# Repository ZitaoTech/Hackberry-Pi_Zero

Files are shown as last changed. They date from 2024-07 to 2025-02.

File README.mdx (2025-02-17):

# Hackberry-Pi_Zero
A handheld Linux terminal using Raspberry pi Zero 2W as Core with 4" 720X720 TFT display and the original BlackBerry Keyboard

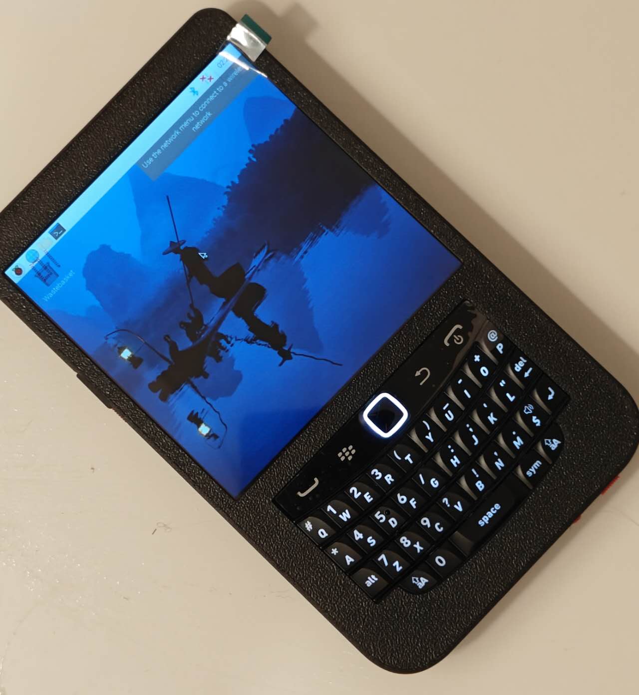
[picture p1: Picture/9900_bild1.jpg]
PTC3
  
  

### [Questions or need more info? Join my Discord Channel!](https://discord.gg/WzPthAmMbP)  
# <a name='About this handheld  '>About this handheld</a>
The main reason why I design and built this handheld cyberdeck is to treat this as a lernning tool and also a funny toy for the hackers. It is powered by a raspberry pi zero 2w and a 4" 720X720 TFT display. 

Here are some **Main Features:**  
**Main Processor**: Only compatible with Raspberry Pi Zero 2w.  
**Display**: 4" 720X720 high resolution TFT display.  
**Dual Swappable battery Design**: Replace your battery in 10 seconds without killing the power!  
**Battery Type**: Nokia BL-5C. You can buy it anywhere in the world.  
**Battery Life**: In my testing: 3.5 hours using the desktop, 5 hours on the commandline.  
**Keyboard Mouse Combo**: Yes, this cyberdeck has keyboard and mouse combo on board. You can choose blackberry Q10 or Q20 or 9900 keyboard.  
**Fully customizable keymap**: You can connect the keyboard with a computer and customizable the keymap through [VIAL](https://get.vial.today/) easily.  
**3 USB2.0 Ports**: This handheld has 3 USB2.0 Ports, you can use it with USB-Stick or 4G Module Dongle or any USB thing.  
**Charging Ampere**: Charge through the Type-C port. 1A charging rate; this handheld can be fully charged within 3 hours.  
**Stemma I2C Port**: This device has a Stemma I2C port on board, you can connect with any I2C sensors.  
**TF card Slot**: There is an external TF card Slot. You can replace your OS image very easily.  

## Block Diagram
Blockdiagramm_HackberryPi_Zero

# <a name='Get started  '>Get started   </a>  
### [Introductionvideo](https://www.youtube.com/watch?v=HDEBzaB1IcY&ab_channel=ZitaoTech)
### How to turn on the HackberryPi?  
Turn the red switch to the **right position** and then press the **red button** to the left side of the red switch to power the USB Hub Controller Chip otherwise the keyboard **can't be used!** At the same time the indicator for the battery voltage will be turned on.    
Turnon  
turnon
# <a name='Keyboard  '>Keyboard</a>
### [Video: Features about the keyboard](https://www.youtube.com/watch?v=mscH1y3DAzE&t=2s&ab_channel=ZitaoTech)
The keyboard type is blackberry Q10 or Q20 keyboard. Both have the same keyboard layout.  
There is a red switch on the left side to decide if the keyboard controller communicates with the HackberryPi or with other device through the USBC-Port underneath.  
The idea about this is you can connect the keyboard with your computer and customize the keymap using [VIAL](https://get.vial.today/) or the handheld can be used as an emergency keyboard mouse combo.  
keyboard
### How to change the keymap?  
Put the red switch to the lower position, connect the keyboard with your computer, open [VIAL page](https://vial.rocks/), then you can customize the keymap yourself.  


# <a name='Different Operating System  '>Different Operating System</a>
You can install Kali, Raspberrypi OS, or Retropi and many other OS into HackberryPi.  
[This page](https://github.com/ZitaoTech/Hackberry-Pi_Zero/tree/main/Screen) will tell you how to install the display driver in a different operating system.  
And [this page](https://github.com/ZitaoTech/Hackberry-Pi_Zero/tree/main/Basic-Setup) will tell you some basic settings on different OS to make HackberryPi have better performance. 
# <a name='Basic Tutorial  '>Basic Tutorial</a>
How to change font size in [terminal](https://askubuntu.com/questions/173220/how-do-i-change-the-font-or-the-font-size-in-the-tty-console)
# <a name='Dimension and Weight  '>Dimension and Weight</a>
Dimension of HackberryPi: 139.4x82x15.7mm  
Weight without battery: 151.7 Gram  
Weight with battery: 189.7 Gram  
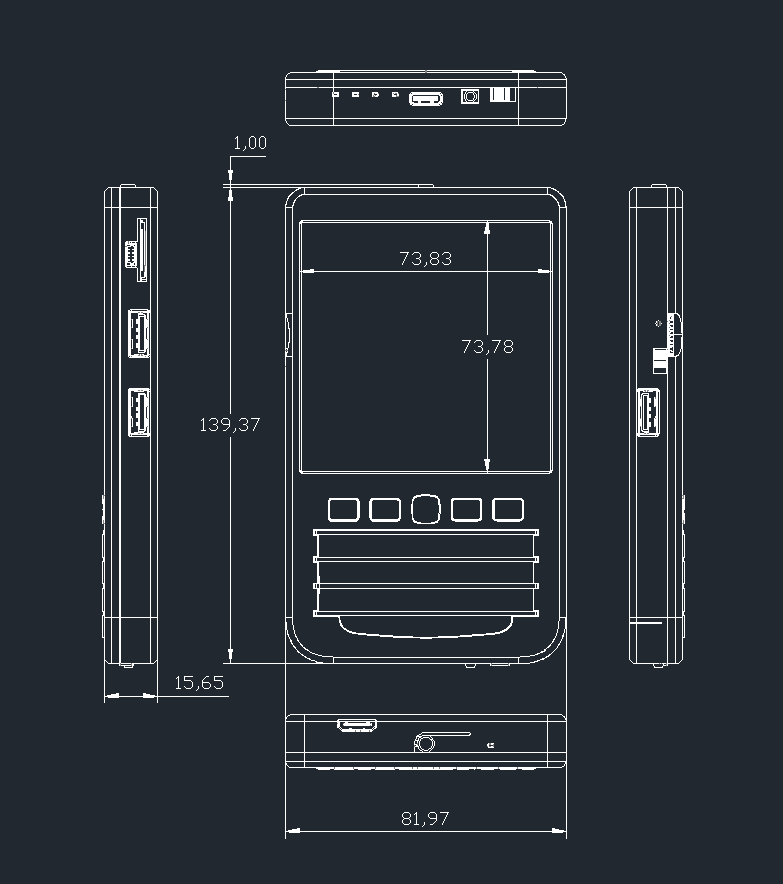
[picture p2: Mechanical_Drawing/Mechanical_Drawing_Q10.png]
  
# <a name='Where to buy  '>Where to buy</a>
### On Elecrow(ship with battery)
[BBQ10 keyboard version](https://www.elecrow.com/hackberrypi-zero-with-q10-keyboard.html)  
[BBQ20 keyboard version](https://www.elecrow.com/hackberrypi-zero-with-bbq20-keyboard.html)  
[BB9900 keyboard version](https://www.elecrow.com/hackberrypi-zero-with-bb9900-keyboard.html)
### On Tindie
[BBQ10 keyboard version](https://www.tindie.com/products/zitaotech/hackberrypi-cyberdeck-handheld-with-bbq10-keyboard/)  
[BBQ20 keyboard version](https://www.tindie.com/products/zitaotech/hackberrypi-cyberdeck-handheld-with-bbq20-keyboard/)  
[BB9900 keyboard version](https://www.tindie.com/products/zitaotech/hackberrypi-cyberdeck-handheld-with-bb9900-kbd/)

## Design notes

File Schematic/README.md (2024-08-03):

### Why no Gerber file?

Some parts like the display and the backlight brightness control chip are custom ordered parts. It's basically impossible to rebuild one even The PCB is ordered from PCBWay or JLCPCB.

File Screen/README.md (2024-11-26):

# This page will tell you the ways to install the display driver in different operating system and some using tips of the display  
### First you need to install the operating system you need into RaspberryPi, this is the [tutorial](https://www.raspberrypi.com/documentation/computers/getting-started.html#installing-the-operating-system), when you choose device, select Raspberry Pi Zero 2W.  
### There is a mini-HDMI port on the top side of HackberryPi. You can connect it with another screen. You can use the following commands to disable/enable the displaying.

```sh
vcgencmd display_power 0
vcgencmd display_power 1
```
### The default backlight brightness of the display after you turn HackberryPi on would be 50%. There is a physical button of the top side of HackberryPi. You can single press it to toggle the backlight of the display. You can also adjust the backlight brightness by long pressing the button: If you first long press the button the backlight brightness will slowly increase to 100%, if you now release the button and long press the button again, the backlight brightness of the display will slowly drop to 10%.  
# Raspberry Pi OS after 04/04/2022 or later  

Add the following line in `/boot/config.txt` in your TF card  

```sh
dtoverlay=vc4-kms-dpi-hyperpixel4sq
``` 
And the `config.txt` file will look like this:  
  
Follow the steps:  
Insert the TF card in to the slot  
Turn on the HackberryPi, the screen will be black, wait until the white led on top stop blinking.  
Turn off the HackberryPi and reboot.  
And then your HackberryPi will run Raspberry Pi OS on the screen.  
RaspberryPiOSfoto

# Kali Linux or Raspberry Pi OS before 04/04/2022   

### Step 1  
Add the following lines in `/boot/config.txt` in your TF card  

```sh
dtoverlay=hyperpixel4
overscan_left=0
overscan_right=0 
overscan_top=0
overscan_bottom=0
framebuffer_width=720
enable_dpi_lcd=1
display_default_lcd=1
dpi_group=2
dpi_mode=87
dpi_output_format=0x5f026
dpi_timings=720 0 20 20 40 720 0 15 15 15 0 0 0 60 0 36720000 4
```
And the `config.txt` file will look like this:  


### Step 2  
Download the `hyperpixel4.dtbo`file in this github page   
Put the `hyperpixel4.dtbo`file into `/boot/overlays`folder  
Now you can insert the TF card in to the slot and your HackberryPi will run Kali Linux on the screen.  
Kalilinux Foto
# RetroPi OS  
### Step 1  
Add the following lines in `/boot/config.txt` in your TF card  

```sh
dtoverlay=hyperpixel4
enable_dpi_lcd=1
dpi_group=2
dpi_mode=87
dpi_output_format=0x5f026
dpi_timings=720 0 20 20 40 720 0 15 15 15 0 0 0 60 0 36720000 4
```
And the `config.txt` file will look like this:  


### Step 2  
Download the `hyperpixel4.dtbo`file in this github page   
Put the `hyperpixel4.dtbo`file into `/boot/overlays`folder  
Now you can insert the TF card in to the slot and your HackberryPi will run RetroPi OS on the screen.  
RetroPiFoto

# DietPi  
DietPi is an extremely lightweight Debian OS, highly optimised for minimal CPU and RAM resource usage. The instruction is made by [Bjoern Franck](https://github.com/bjoernfranck)  
You can view the tutorial at this [page](https://github.com/bjoernfranck/HackberryPi/tree/main/DietPi)  


# Troubleshoot  
  
You might found your display flickering or flashing like this on the picture. This happens when the display driver is powered but no image signal coming through.  
It can usually happen when you flash a new SD card or wake up from screen blanking.  
The display can recover itsself when you put the device running like 1 hour, but you need to disable screen blanking first.  
Here are steps you need to do to disable screen blanking:  
[On RaspberryPi OS](https://github.com/raspberrypi/documentation/blob/develop/documentation/asciidoc/computers/configuration/screensaver.adoc)  
[On Kali](https://superuser.com/questions/1185747/how-do-i-disable-the-screensaver-lock-in-kali-linux)

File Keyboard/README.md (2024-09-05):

hackberrypiq10_vial.uf2: default firmware file for the keyboard controller chip(RP2040) on HackberryPi with BBQ10 keyboard  
hackberrypiq20_vial.uf2: default firmware file for the keyboard controller chip(RP2040) on HackberryPi with BBQ20 keyboard  
layout_hackberrypi_q10.vil: default keyboard layout setting file on VIAL for HackberryPi with BBQ10 keyboard  
layout_hackberrypi_q20.vil: default keyboard layout setting file on VIAL for HackberryPi with BBQ20 keyboard  

### How to use the .vil file?  
Let's say that you changed many keycodes and want to reset the keyboard layout  
First download vial app from [vial](https://get.vial.today/) homepage  
Install the vial app and open the app  
Then connect yor computer with Hackberry and in menu **file**->**Load saved layout** and select the .vil file, the keyboard layout will be reset.  

## Default Layout and Layers
### Layer0:
Keymap_Layer0

### Layer 1:
Keymap_Layer1

### Layer 2:
Keymap_Layer2

## Other Features
When holding Ctrl, mouse dpix2  
When holding Alt, mouse dpi/2  
When capslock, The trackpadbacklight will be turned on for Q10 version, and the backlight of the top row keys will be turned on for Q20 version. meanwhile the mouse will work as scroll wheel, you can browse a file quickly.  

The backlight of the keyboard will be turned off if you don't type anything for 30 seconds.

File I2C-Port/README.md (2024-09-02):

## How to use the I2C port on HackberryPi
First, don't enable I2C interface in raspi-config. Because the default I2C pins are used by the display. If you enable the I2C interface, the screen will be black. You need to connect HackberryPi to another display with an HDMI cable to disable the I2C interface to make it back.

The I2C pins on HackberryPi are: GPIO10 for I2C_SDA and GPIO11 for I2C_SCL  

There is a [STEMMA QT](https://learn.adafruit.com/introducing-adafruit-stemma-qt/what-is-stemma-qt) port on board, which means you can connect a sensor board with STEMMA QT port with HackberryPi through the I2C interface.  
On HackberryPi you need to open a terminal, and type:
``` sh
sudo ln -s /dev/i2c-11 /dev/i2c-1
```
to symlink i2c-11 to i2c-1 to fool any I2C devices into talking to the alternate one rather than the standard one.

Then you can just type this in a terminal:
``` sh
sudo i2cdetect -y 1
```
to check if the sensor is available.



If you want to undo this, you can simply delete the i2c-1 symlink file by typing in the terminal:
``` sh
sudo rm /dev/i2c-1
```

## One example about using this I2C port:  
[hack-environment-monitor](https://github.com/chriswilson2020/hack-environment-monitor/tree/main)

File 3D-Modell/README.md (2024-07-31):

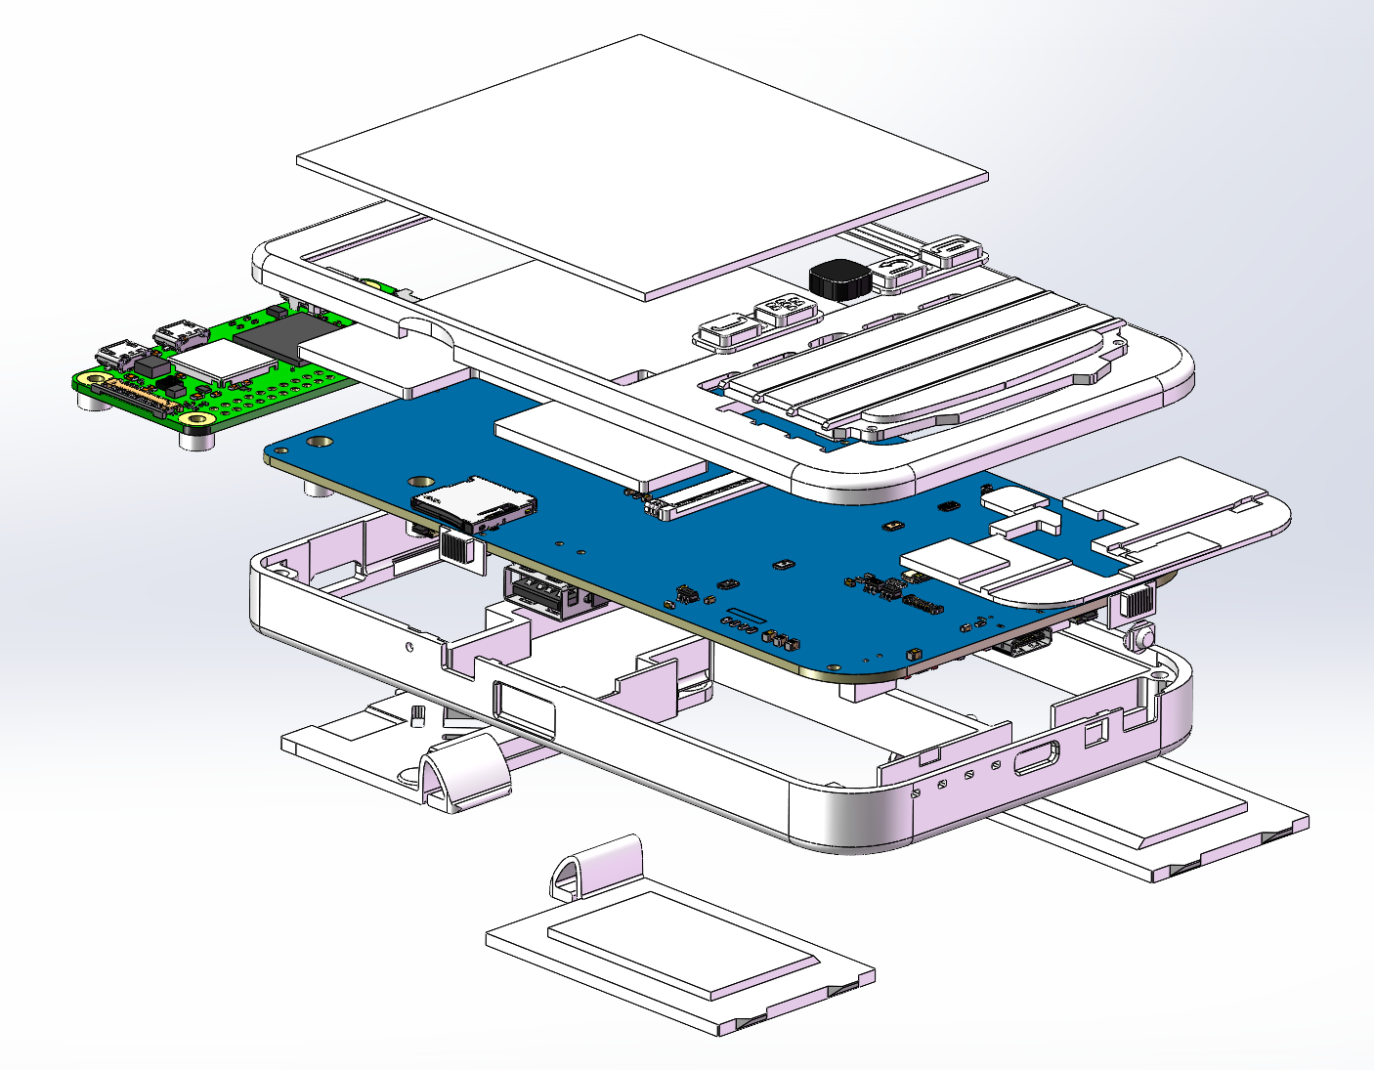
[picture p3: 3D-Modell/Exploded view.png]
exploded view


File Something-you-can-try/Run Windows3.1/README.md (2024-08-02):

### First, download dosbox app by

```sh
sudo apt-get install dosbox
```

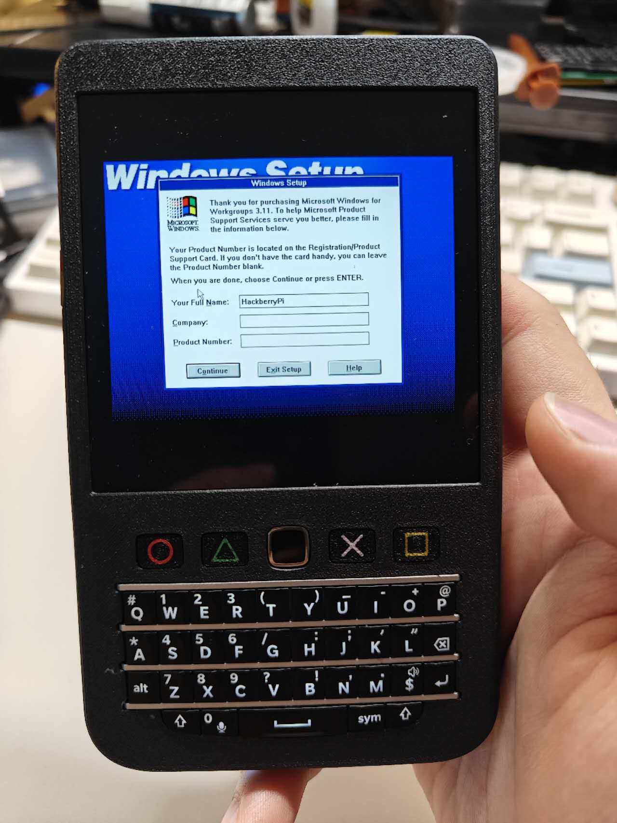
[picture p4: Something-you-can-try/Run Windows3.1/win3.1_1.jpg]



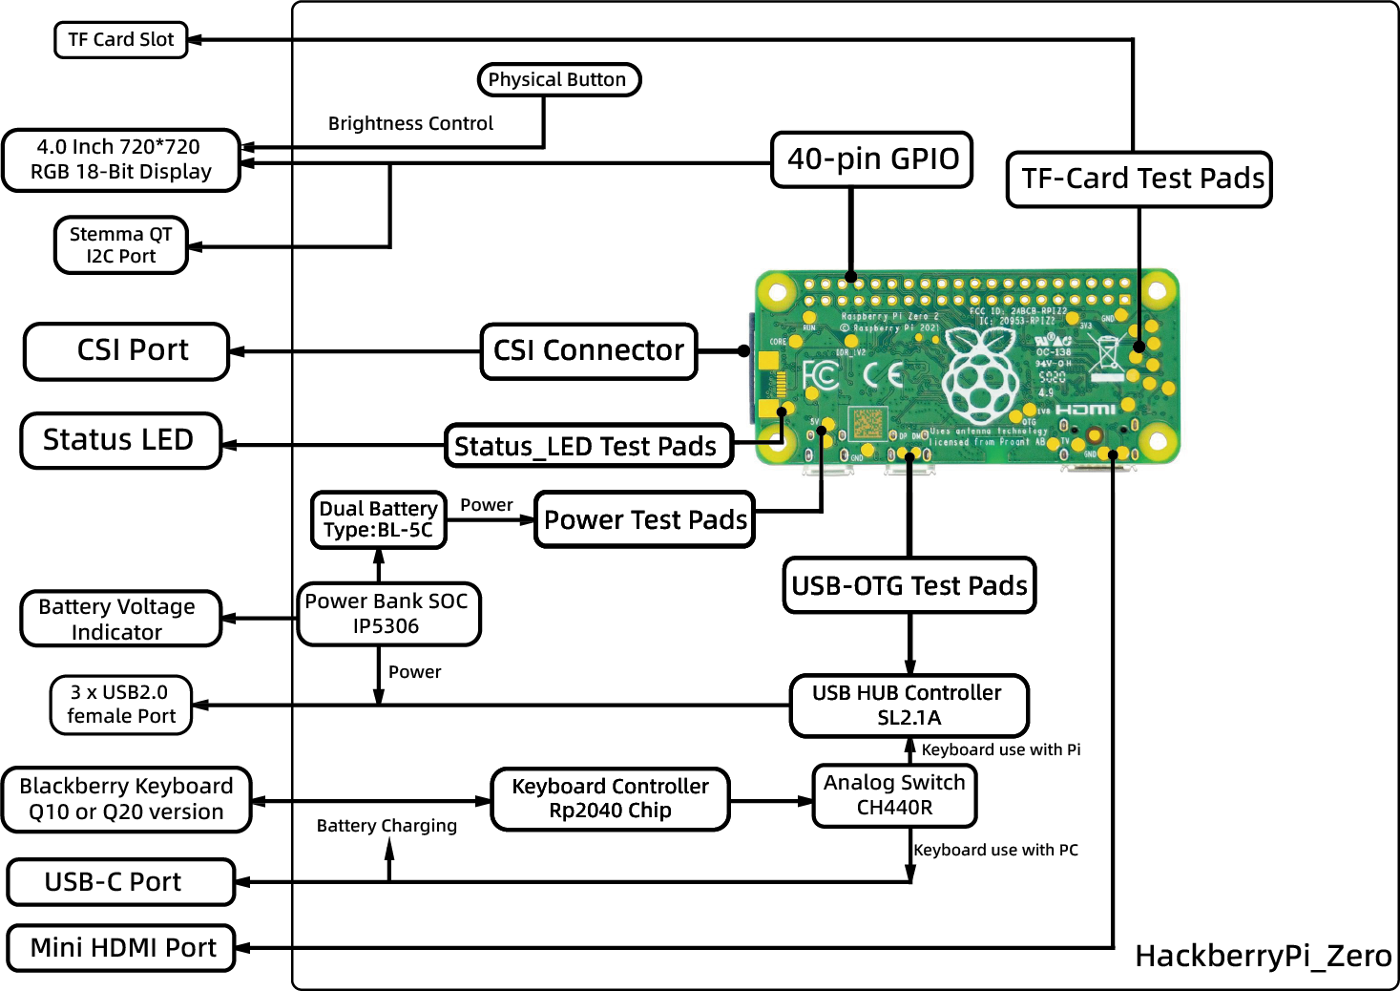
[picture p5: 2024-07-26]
Picture/Blockdiagramm_HackberryPi_Zero.png

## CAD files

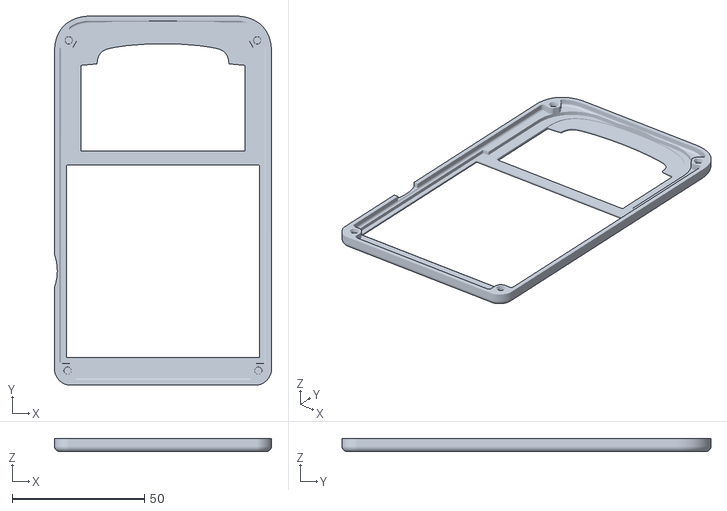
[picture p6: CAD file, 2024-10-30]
3D-Modell/Uppercase_9900_keyboard_version.stl
82.0 x 139.4 x 4.95

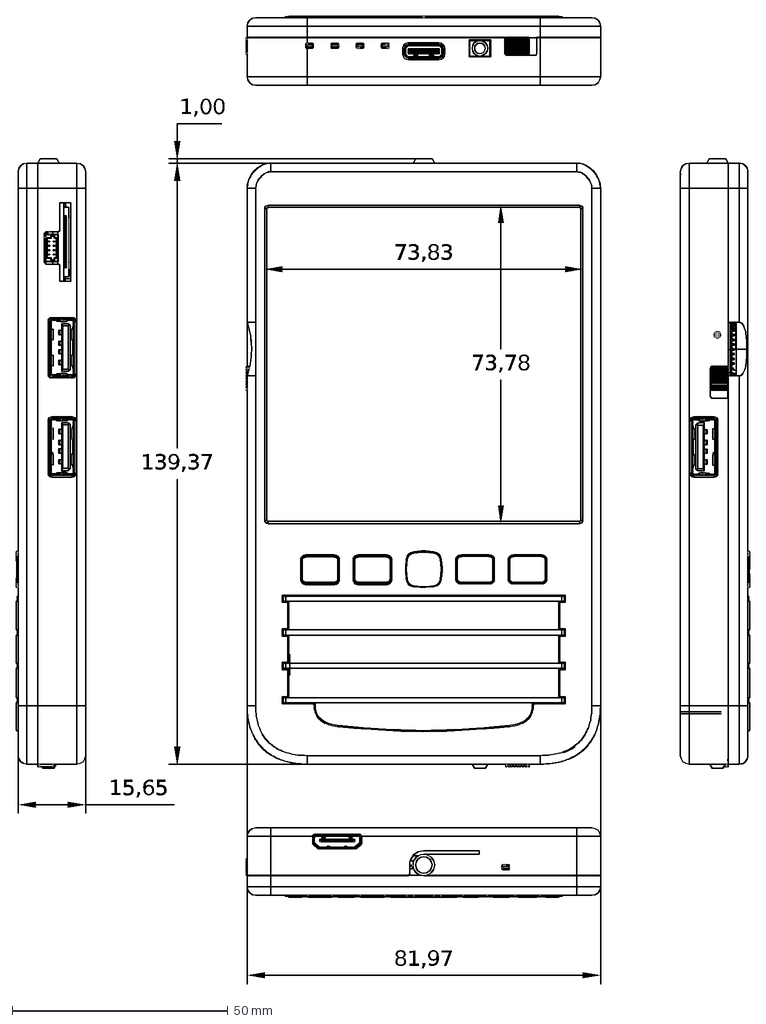
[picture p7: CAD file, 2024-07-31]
Mechanical_Drawing/HackberryPi_Q10.dxf
15,65
139,37
1,00
73,83
73,78
81,97

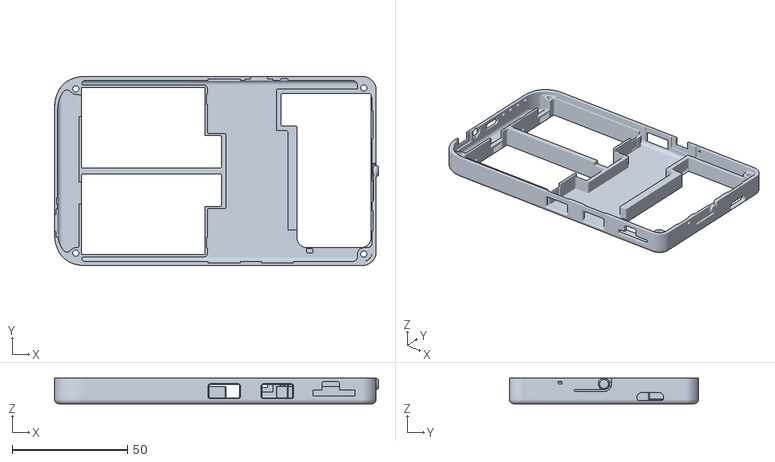
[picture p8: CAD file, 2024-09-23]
3D-Modell/Hackberry_LowerCase_fits_for_3_version.stl
140.4 x 82.0 x 11.1

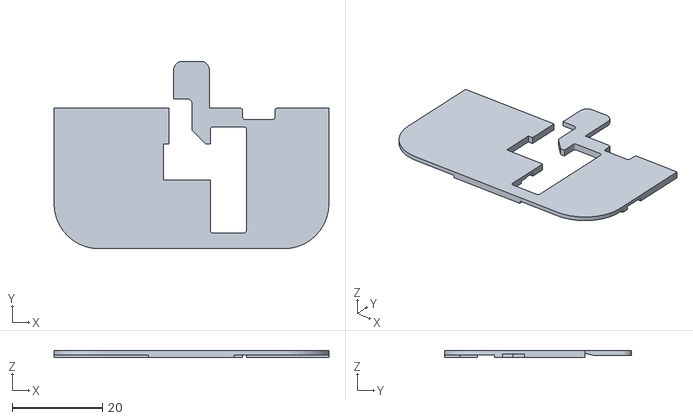
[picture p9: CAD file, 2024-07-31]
3D-Modell/Under_keyboard_support_Q10.STL
61.0 x 41.6 x 1.55

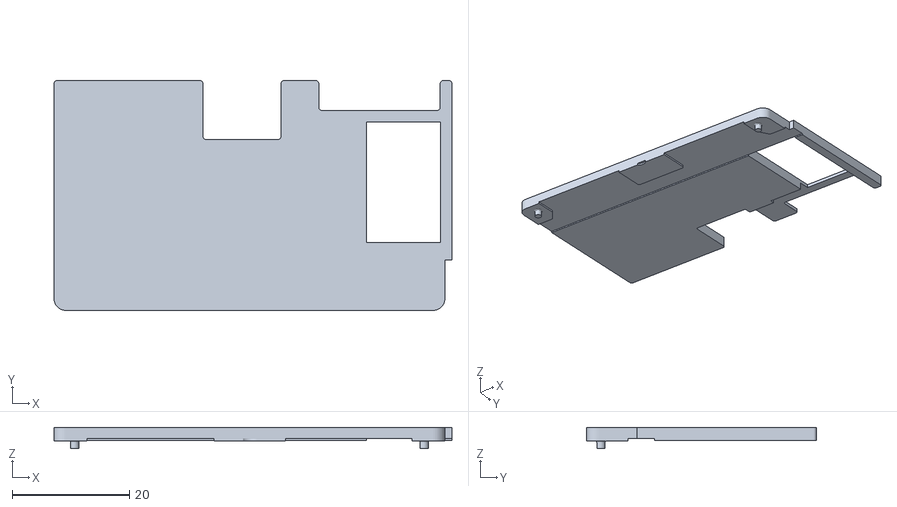
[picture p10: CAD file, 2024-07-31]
3D-Modell/Under_keyboard_support_Q20.STL
67.8 x 39.1 x 3.60

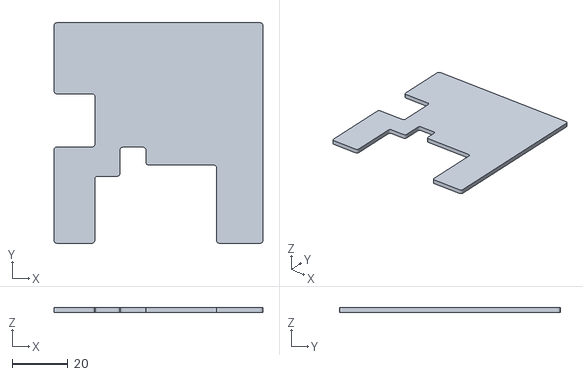
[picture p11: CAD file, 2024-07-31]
3D-Modell/Display_support.STL
74.8 x 79.0 x 1.95

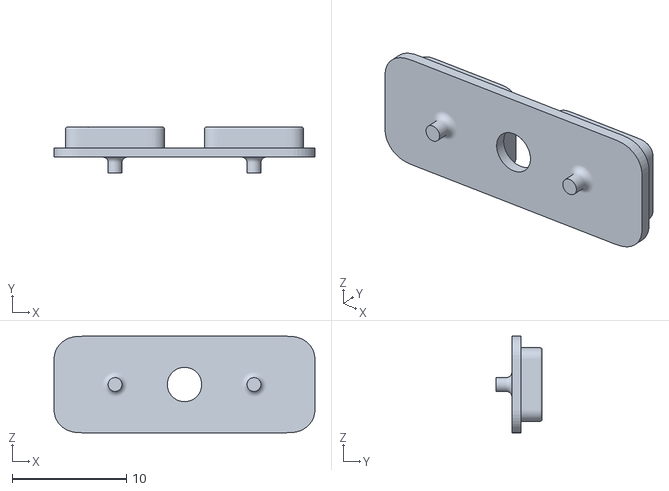
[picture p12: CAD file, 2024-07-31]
3D-Modell/Top_row_key.STL
22.8 x 4.05 x 8.43

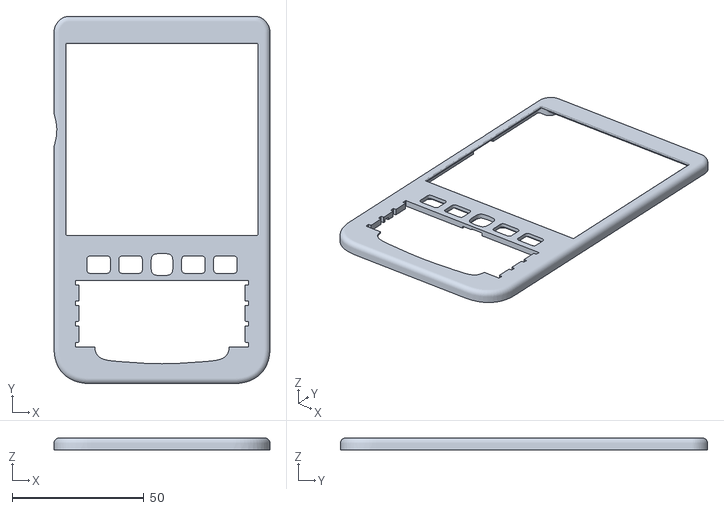
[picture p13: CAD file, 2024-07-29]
3D-Modell/Uppercase_Q10_keyboard_version.STL
82.0 x 139.4 x 4.60

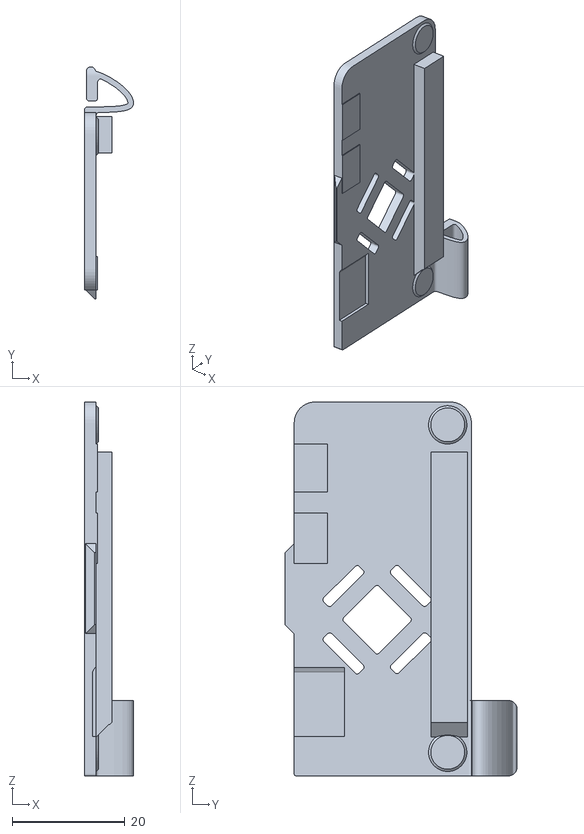
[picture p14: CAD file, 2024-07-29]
3D-Modell/RPI_Cover.STL
8.70 x 41.2 x 66.3

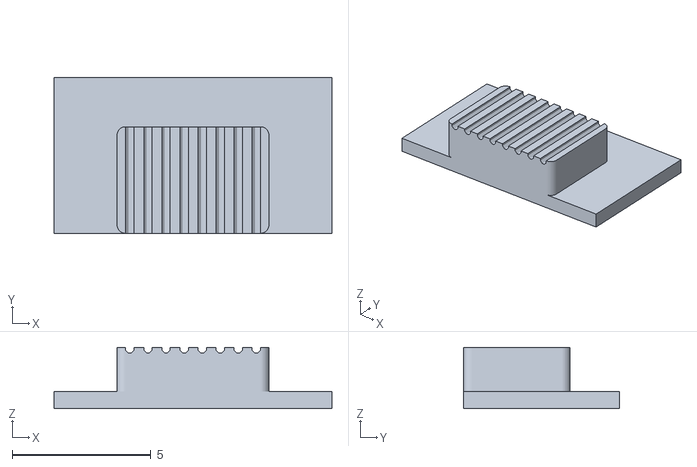
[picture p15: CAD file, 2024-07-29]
3D-Modell/Red_Switch.STL
10.0 x 5.60 x 2.19

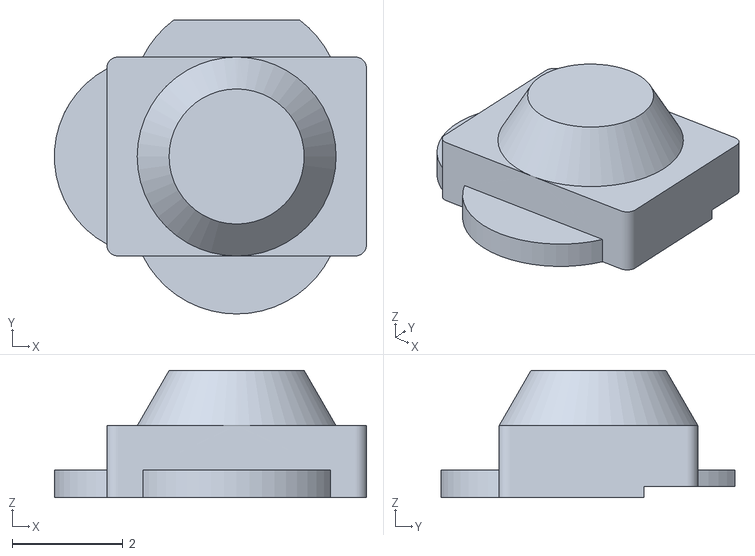
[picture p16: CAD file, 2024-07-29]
3D-Modell/Red_key.STL
5.65 x 5.32 x 2.30

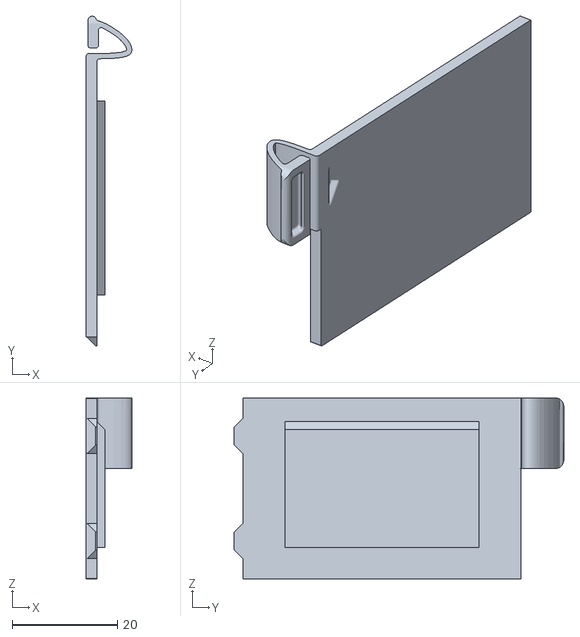
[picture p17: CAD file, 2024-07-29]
3D-Modell/Battery_Cover_Left.STL
8.70 x 62.7 x 34.4

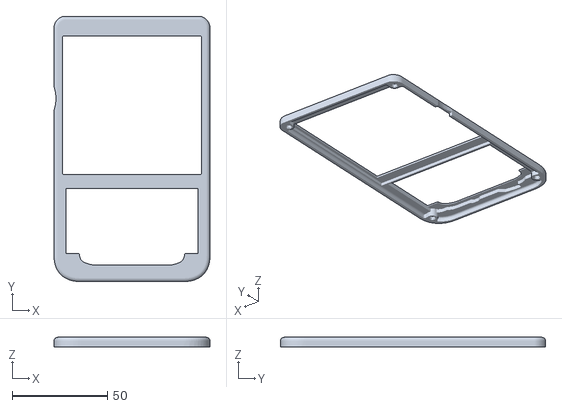
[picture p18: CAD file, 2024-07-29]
3D-Modell/Uppercase_Q20_keyboard_version.STL
82.0 x 139.4 x 5.00

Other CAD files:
3D-Modell/Battery_Cover_Right.STL

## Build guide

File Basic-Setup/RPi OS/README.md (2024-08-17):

### [How to increase the swapfile in RPi OS](https://pimylifeup.com/raspberry-pi-swap-file/)
For HackberryPi, I would recommend increasing the swap size to 2048MB(2GB)

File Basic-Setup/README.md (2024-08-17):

### This page collects some issues that you will meet with different OS and some ways to solve them out like how to increase the performence of Rpi Zero2w

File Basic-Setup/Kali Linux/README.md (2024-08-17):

This is a important step, otherwise the zero2w often gets frozen while sudo apt update  
### [How to increase the swapfile in Kali Linux](https://miloserdov.org/?p=2667)
For HackberryPi, I would recommend increasing the swap size to 2048MB(2GB)

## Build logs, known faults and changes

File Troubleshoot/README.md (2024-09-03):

I have receveied several reports that the keyboard will shut down or not work after about 30 seconds after the red key is pressed with battery powered.  

I will explain why this would happen in this page:  
On HackberryPi the 5V power is generated by the power bank SOC IP5306 as you can see from the schematic  
One feature about IP5306 or any other power bank is that it will detect the load current, if the load current is too small, the 5V will be cut off by IP5306. On the datasheet it says the detect value is 45ma.
  
On HackberryPi, only the USB HUB controller chip SL2.1A and the 3 USB ports are powered by 5V.
That means, once you press the red key next to the power switch, the USB HUB Controller chip will be powered, and then the RaspberryPi will receive the signal from the keyboard controller RP2040.  
And there is another feature about the USB HUB controller chip SL2.1A, it will draw about 60 ma current when it's connected to a USB Host and a USB Slave. Once you shut down the Pi and SL2.1A will lose the USB Host, now it draws only 20 ma current. So want I want: once you press the red key, SL2.1A draws more current than the minium load current of IP5306, and the 5V will be continuously genereted. But the fact is that **there is a big difference of this value between different IP5306**, some has **45ma**, and some has **more than 70ma**. Which can cause the shut down of the 5V.  

### Solution for this: Plug a tiny USB device like a supertiny USB Stick(or any other USB device)
### into one of the 3 USB ports of HackberryPi so IP5306 can continuously output the 5V.  

### Also important to note: Once you plug the USB device, the IP5306 will continuously output 5V, you need to double tap the red key to cut the 5V power after you shut down HackberryPi.

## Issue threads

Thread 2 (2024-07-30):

Release PCB design and BOM

iraqigeek, 2024-07-30:
Hi,
I found about the Hackberry via youtube, and wanted to make one, but I see you haven't released the design files. I saw you're selling fully assembled ones on your Tindie, but I wanted to make my own. Would you mind releasing the PCB design and BOM? Alternatively, just release the BOM and make the PCB available on your Tindie shop for people like me who want to make their own.
Thanks!

ZitaoTech, 2024-07-31:
Hello,

I will release the schematic but not the Gerber file, because some components are custom ordered like the display and the backlight control chip. Even if you have the file it will be difficult and will cost more than the price I set to make one yourself.

Zitao

securitylion, 2024-08-07:
Any chance you will sell just the custom PCBs so we can buy, print, and assemble ourselves?

LeonLeeXiang, 2024-08-12:
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

你好，我也是在德国的留学生，正好想用BBkey做一个legion go 的手柄键盘试一试，请问键盘硬件是从国内订购的么？

ZitaoTech, 2024-08-12:
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

电路板我自己设计的 PCB是嘉立创生产的

ZitaoTech, 2024-08-12:
> Any chance you will sell just the custom PCBs so we can buy, print, and assemble ourselves?

The assembly is too difficult for a non-tech person to accomplish, actually

vicliu624, 2024-09-16:
could you sell the PCB separately on on your Tindie， because I can remove some of the parts from my old phone?

LuizGaronce, 2024-12-27:
Hello everything is fine?
Is it possible for you to make the Schematic, PCB and Gerber KiCAD files available, please? I can find replacements for the missing parts.

Thanks.   : )

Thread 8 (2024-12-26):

Too slow :(

mattfaraday, 2024-12-26:
The device is awesome. But it's just too slow. You can't run browsers etc on it as it even warns you about the lack of RAM for the job.
Have you tried any other single board computers the same form factor? like Radxa Zero 3 W

ZitaoTech, 2024-12-26:
That's right, the biggest issue is rpi02w has only 512MB ram, it would be much better if it has 1GB ram. Also, are you running on 64bit OS? I found 32bit OS should be faster on rpi2w and you can try dietpi OS, which is more lightweighted. And for browser I would recommend web browser in terminal like w3m.
Radxa zero3w doesn't support the dpi interface. It's difficult to drive the screen

huuck, 2024-12-27:
Does dietPi come in a 32bit flavour? Could not find it anywhere on their website.

markuman, 2025-01-09:
I guess CM4 version would solve the issue.

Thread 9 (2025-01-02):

Board upgrades?

0verambitious, 2025-01-02:
I understand this was designed specifically for the pi zero 2w
But have you put any thought into maybe a revision for using maybe a radxa or soemthing with more ram? 4gb of ram would be amazing!
Either way: amazing work you've done here. Love the device 🙏🏼🙏🏼

ZitaoTech, 2025-01-02:
Yes I designed another version for rpi4B. Just launched last week but haven't uploaded a video on YouTube

https://github.com/ZitaoTech/HackberryPi-4B

0verambitious, 2025-01-02:
Joined the waitlist on tindie! Very cool stuff. 💯💯

oneguynick, 2025-01-11:
Are any of the Zero 2w boards pin compatible with this? Has anyone tested?

nin187, 2025-02-04:
Can I swap RPi zero 2w into Orange Pi zero 2W(4GB ram)?

CodeHedge, 2025-02-04:
> Can I swap RPi zero 2w into Orange Pi zero 2W(4GB ram)?

No, they don't have the same test pad locations

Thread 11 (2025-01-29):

Battery status reporting in software

jwoglom, 2025-01-29:
Hi Zitao, really awesome work on this cyberdeck. It is such a cool device. I was wondering whether there is any ability in the current design of the Hackberry Pi to view the battery status level in software, sent in some way via the GPIO pins? The battery status lights on the bottom of the case are nice for a general indication of how much capacity is available but I could imagine it being useful to do things like automatically turn the device off safely or dim screen brightness if battery is low. Totally fine if the current design doesn't accommodate this, but could be a nice addition for a theoretical V2 product.

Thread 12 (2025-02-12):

Any chance of upgrade kit from RPi02w to RPi4?

nin187, 2025-02-12:
I bought hackberry pi zero 2w, and still waiting for the arrival.
As there are some comments that RPi02w is too slow, so I want to upgrade to RPi4 8GB which I already have, in case RPi02w is too slow to use.
Is there any chance of launching upgrade kit for whom already owns hackberry pi zero 2w like me?

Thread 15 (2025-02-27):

After switch off my hackberry is not turning on. It's showing like blank screen

mrnextgen, 2025-02-27:

CodeHedge, 2025-02-27:
Have you checked your SD card?

If you have a spare SD card I would follow the guide on the GitHub for installing an OS. Then booting into that as a sanity check.

mrnextgen, 2025-02-27:
Yes i have spare one . I write A new os in this SD card but still same .
Top side led not blinking. Keyboard light and keyboard not working.only
showing a blank screen

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

araskurd, 2025-03-07:
I have the same problem and it has not been solved for me yet :(

freitas666, 2025-03-19:
> I have the same problem and it has not been solved for me yet :(

Some update bro?

astearon, 2025-04-04:
I have the same situation. The SD has the stock RPi OS x64 version with "dtoverlay=vc4-kms-dpi-hyperpixel4sq" added to the config.
The white LED top indicator light does not turn on and the cpu is not even warm.

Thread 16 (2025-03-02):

Case update batteries.

davidwowa, 2025-03-02:
I will update my hackberry with batteries with more capacity, but it not possible to install, because no place by inserting. Is it possible to make the battery compartment about half a millimeter larger? The arrow in the picture shows exactly where.

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

thank you.

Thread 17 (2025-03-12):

Just got my Hackberry :)

ZachLavinci23, 2025-03-12:
When I turn on the Hackberry, the screen powers on but displays nothing, and the system doesn't boot.

I've already tried two different images on two separate SD cards. Could it be attempting to boot from one of the USB ports, or is there something else I can try to get it running?

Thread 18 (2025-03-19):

Black Screen on Kali Linux

freitas666, 2025-03-19:
I followed the procedure from https://github.com/ZitaoTech/Hackberry-Pi_Zero/tree/main/Screen. The Hackberry shows Kali Linux starting, but then the screen goes black and nothing shows. I have normal SSH access, but the screen stays black on the Hackberry itself. How can I resolve this?

freitas666, 2025-03-19:
Probably some bug in new kali linux 2025 (19/03/2025)...... i tested with old version and worked great!!!

sportyooz, 2025-04-09:
Im having the same issue changed OS not able to get screen to load connected thru SSH all the updated and drivers for the screen

venatiodecorus, 2025-04-25:
i got a black screen on the latest version so i downloaded 2024.4 and got it to boot to desktop, but wifi isn't working. what version did you use @freitas666 ?

kadirkurt, 2025-06-04:
## 💪 Fixing Display and Wi-Fi Issues on Kali Linux (Raspberry Pi Zero 2 W)

**Tested Image:**
`kali-linux-2025.1c-raspberry-pi-zero-2-w-armhf.img.xz`

This guide explains how to resolve two common issues when using Kali Linux on a Raspberry Pi Zero 2 W:

1. 💥 **Display goes black right before the desktop loads**
2. 📶 **Wi-Fi (wlan0) appears as "unmanaged" in NetworkManager**

---

### ✅ 1. Display Fix — Black Screen Before Desktop

If your DPI display (e.g. Hackberry Pi or HyperPixel 4) shows boot text but turns black when the desktop should appear, apply the following configuration.

Edit `/boot/config.txt` and replace the relevant section with:

```ini
# Enable custom DPI display (720x720)
dtoverlay=hyperpixel4

disable_overscan=1
overscan_left=0
overscan_right=0
overscan_top=0
overscan_bottom=0

framebuffer_width=720
framebuffer_height=720

enable_dpi_lcd=1
display_default_lcd=1
dpi_group=2
dpi_mode=87
dpi_output_format=0x5f026
dpi_timings=720 0 20 20 40 720 0 15 15 15 0 0 0 60 0 36720000 4

# IMPORTANT: Disable KMS to prevent black screen
# Comment out or remove the following line if present:
# dtoverlay=vc4-kms-v3d
```

> 🧐 Without disabling KMS, the system may boot to a black screen due to driver conflict with DPI displays.

---

### ✅ 2. Wi-Fi Fix — `wlan0` Unmanaged in GUI

If you see `wlan0` listed as **unmanaged** and can't scan or connect to Wi-Fi in the desktop environment:

#### 🧹 Step 1: Enable management of interfaces in NetworkManager

Edit the configuration:

```bash
sudo nano /etc/NetworkManager/NetworkManager.conf
```

Ensure it contains:

```ini
[main]
plugins=ifupdown,keyfile

[ifupdown]
managed=true
```

#### 🧹 Step 2: Clean `/etc/network/interfaces`

Edit:

```bash
sudo nano /etc/network/interfaces
```

And make sure it only contains:

```ini
auto lo
iface lo inet loopback
```

> Remove any lines referencing `wlan0`.

#### 🔄 Step 3: Restart NetworkManager

```bash
sudo systemctl restart NetworkManager
```

#### 🛠️ Step 4: Force `wlan0` to be managed (if still unmanaged)

If `wlan0` still shows as unmanaged, fix it manually:

```bash
nmcli device set wlan0 managed yes
```

---

### 📱 Now Connect to Wi-Fi

You can now connect using:

* `nmtui` (text-based interface)
* GUI (click the Wi-Fi icon and select your network)

---

### 🧚‍♂️ Tested With

* **Image:** `kali-linux-2025.1c-raspberry-pi-zero-2-w-armhf.img.xz`
* **Device:** Raspberry Pi Zero 2 W
* **Display:** HyperPixel 4-compatible DPI screen (720x720)
* **Kernel:** 6.x ARMHF (32-bit)
* **Interface:** XFCE

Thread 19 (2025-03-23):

Looking for a squared USB-C display with specific dimension to replace the default display of the HackBerry Pi Zero.

Marietto2008, 2025-03-23:
Hello to everyone.

I've bought and opened the Hackberry-Pi_Zero.

Let's give a look at the pictures below. This is how how the display (4" 720X720 TFT) is attached to the board (Raspberry Pi Zero) :

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

my idea is to remove that display and to use one USB-C display of the same inches. For example with this model :

https://www.waveshare.com/product/raspberry-pi/displays/3.5inch-hdmi-lcd-e.htm

I'm sure that in this case,FreeBSD will be able to boot and run. Anyway,I'm looking for a little bit better display because the original one that I want to remove is 4 inches. The new one is 3,5 inches and it's too short. There's some wasted "screen" space. I would like to find a display at least with the same inches,but that can replace perfectly the default one.

The dimensions of the default display is :

width = 7.5 cm

height = 8 cm

the new display should fit perfectly inside this frame :

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

I'm actively looking for a squared USB-C display that can match those dimensions. I will find it faster with your help. Thanks.

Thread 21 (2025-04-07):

Case dimentions issue

astearon, 2025-04-07:
The top cover that sits above the RPi has a thicker band that sits on top of the GPIO pins.

Unfortunately that wide piece can slide up and down a bit due to tolerances or overall cover wear and tear resulting in it bumping against an inductor.

You can see a similar damage in the following thread with pictures explaining where the damage is being done:

[470nH SMT inductor](https://forum.core-electronics.com.au/t/damaged-raspberry-pi-zero-2-w/14647)

Solution for this is to create a gap in the band so that the inductor can be avoided in that area.

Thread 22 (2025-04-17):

Add Telephony Support (Voice + Mobile Data) for Raspberry Pi

matheuscamarques, 2025-04-17:
Pull Request: Add Telephony Support (Voice + Mobile Data) for Raspberry Pi

Summary

This PR introduces the foundational support to turn a Raspberry Pi into a full-fledged telephony-enabled device, including:

Audio Output (for voice)

Microphone Input (for capturing voice)

3G/4G/5G Mobile Connectivity

1. Audio Output Support

Proposal:

Integrate an I2S DAC module (e.g., PCM5102A or WM8960) to provide high-quality audio output.

Support 3.5mm audio jack or speaker output.

Rationale:

The onboard audio output of Raspberry Pi is limited in quality and features.

I2S DAC offers better performance and reliability for voice communication.

Expected Implementation:

ALSA configuration via asound.conf

Device management using amixer, pulseaudio, or pipewire

2. Microphone Input Support

Proposal:

Add support for USB microphones or I2S-based modules like INMP441 or WM8960 with mic input.

Allow recording via arecord or other audio capture tools.

Rationale:

Required for two-way voice communication and optional voice command capabilities.

Optional Enhancements:

Integration with a wake-word engine or voice assistant SDK

3. Mobile Network (3G/4G/5G) Support

Proposal:

Add support for common cellular modem modules such as SIM7600, Quectel EC25, or Quectel RM500Q.

Automatic detection over USB.

Scripts to configure PPP or use ModemManager for mobile data connections.

Advanced Features (Optional):

Support for voice calls and SMS via AT commands, if the module supports GSM voice.

Example AT Commands:

ATD+5531999999999; # Dial call ATA # Answer call ATH # Hang up call

Integration Requirements

Add detailed documentation explaining compatible modules and wiring instructions.

Provide setup/configuration scripts.

Verify dependencies (e.g., alsa-utils, ppp, modemmanager, etc.) in installation script (install.sh or equivalent).

Conclusion

This PR sets the foundation for advanced telephony functionality, such as:

Voice calls

SMS support

Internet access via SIM card

Voice recognition / control

Full offline capability (no Wi-Fi needed)

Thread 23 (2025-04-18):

No 2nd button on button

acidvegas, 2025-04-18:
My HackBerry doesnt have the 2nd red button on the bottom to enable the keyboard. What do I do cause my keyboard is not working currently. I only have thr slide power button on the bottom of mine

acidvegas, 2025-04-18:
Had to fully charge the device. Got it working

Closed 2025-04-18.

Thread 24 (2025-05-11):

Mouse not working?

mattfaraday, 2025-05-11:
Hi

I just picked this device up again to play with, I used it only a couple of times and put it back in it's box.
But now the mouse doesn't work. The keyboard does because I can type things, and yeah I pressed the usb hub power button on boot-up.
But the mouse doesn't move at all.

I put back in the original SD card that came with it, and same the mouse doesn't move
do you think it's broken?
is there something I can do or check to make the mouse work?

It's the 9900 version.

abawany, 2025-08-06:
I had this problem - it turns out that when 'shift' is pressed (in my case with the Q20 keyboard, I believe it is the 'vessel' key on the top left row next to the BB key), the mouse no longer responds. When this is unset, it begins to work again.

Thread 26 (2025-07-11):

rs232 Port

Amock1610, 2025-07-11:
Is it possible to retrofit a serial connection (RS232)?
Are the UART pins still free?
Could I add an rs232 shield with a customized housing?
Something Like this. [](https://www.reichelt.de/de/de/shop/produkt/raspberry_pi_-_konverter_gpio_auf_seriell-154883?PROVID=2788&gQT=2)

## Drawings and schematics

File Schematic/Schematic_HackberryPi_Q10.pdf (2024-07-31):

# 1 LEDA 40 41 41 42 42

720x720

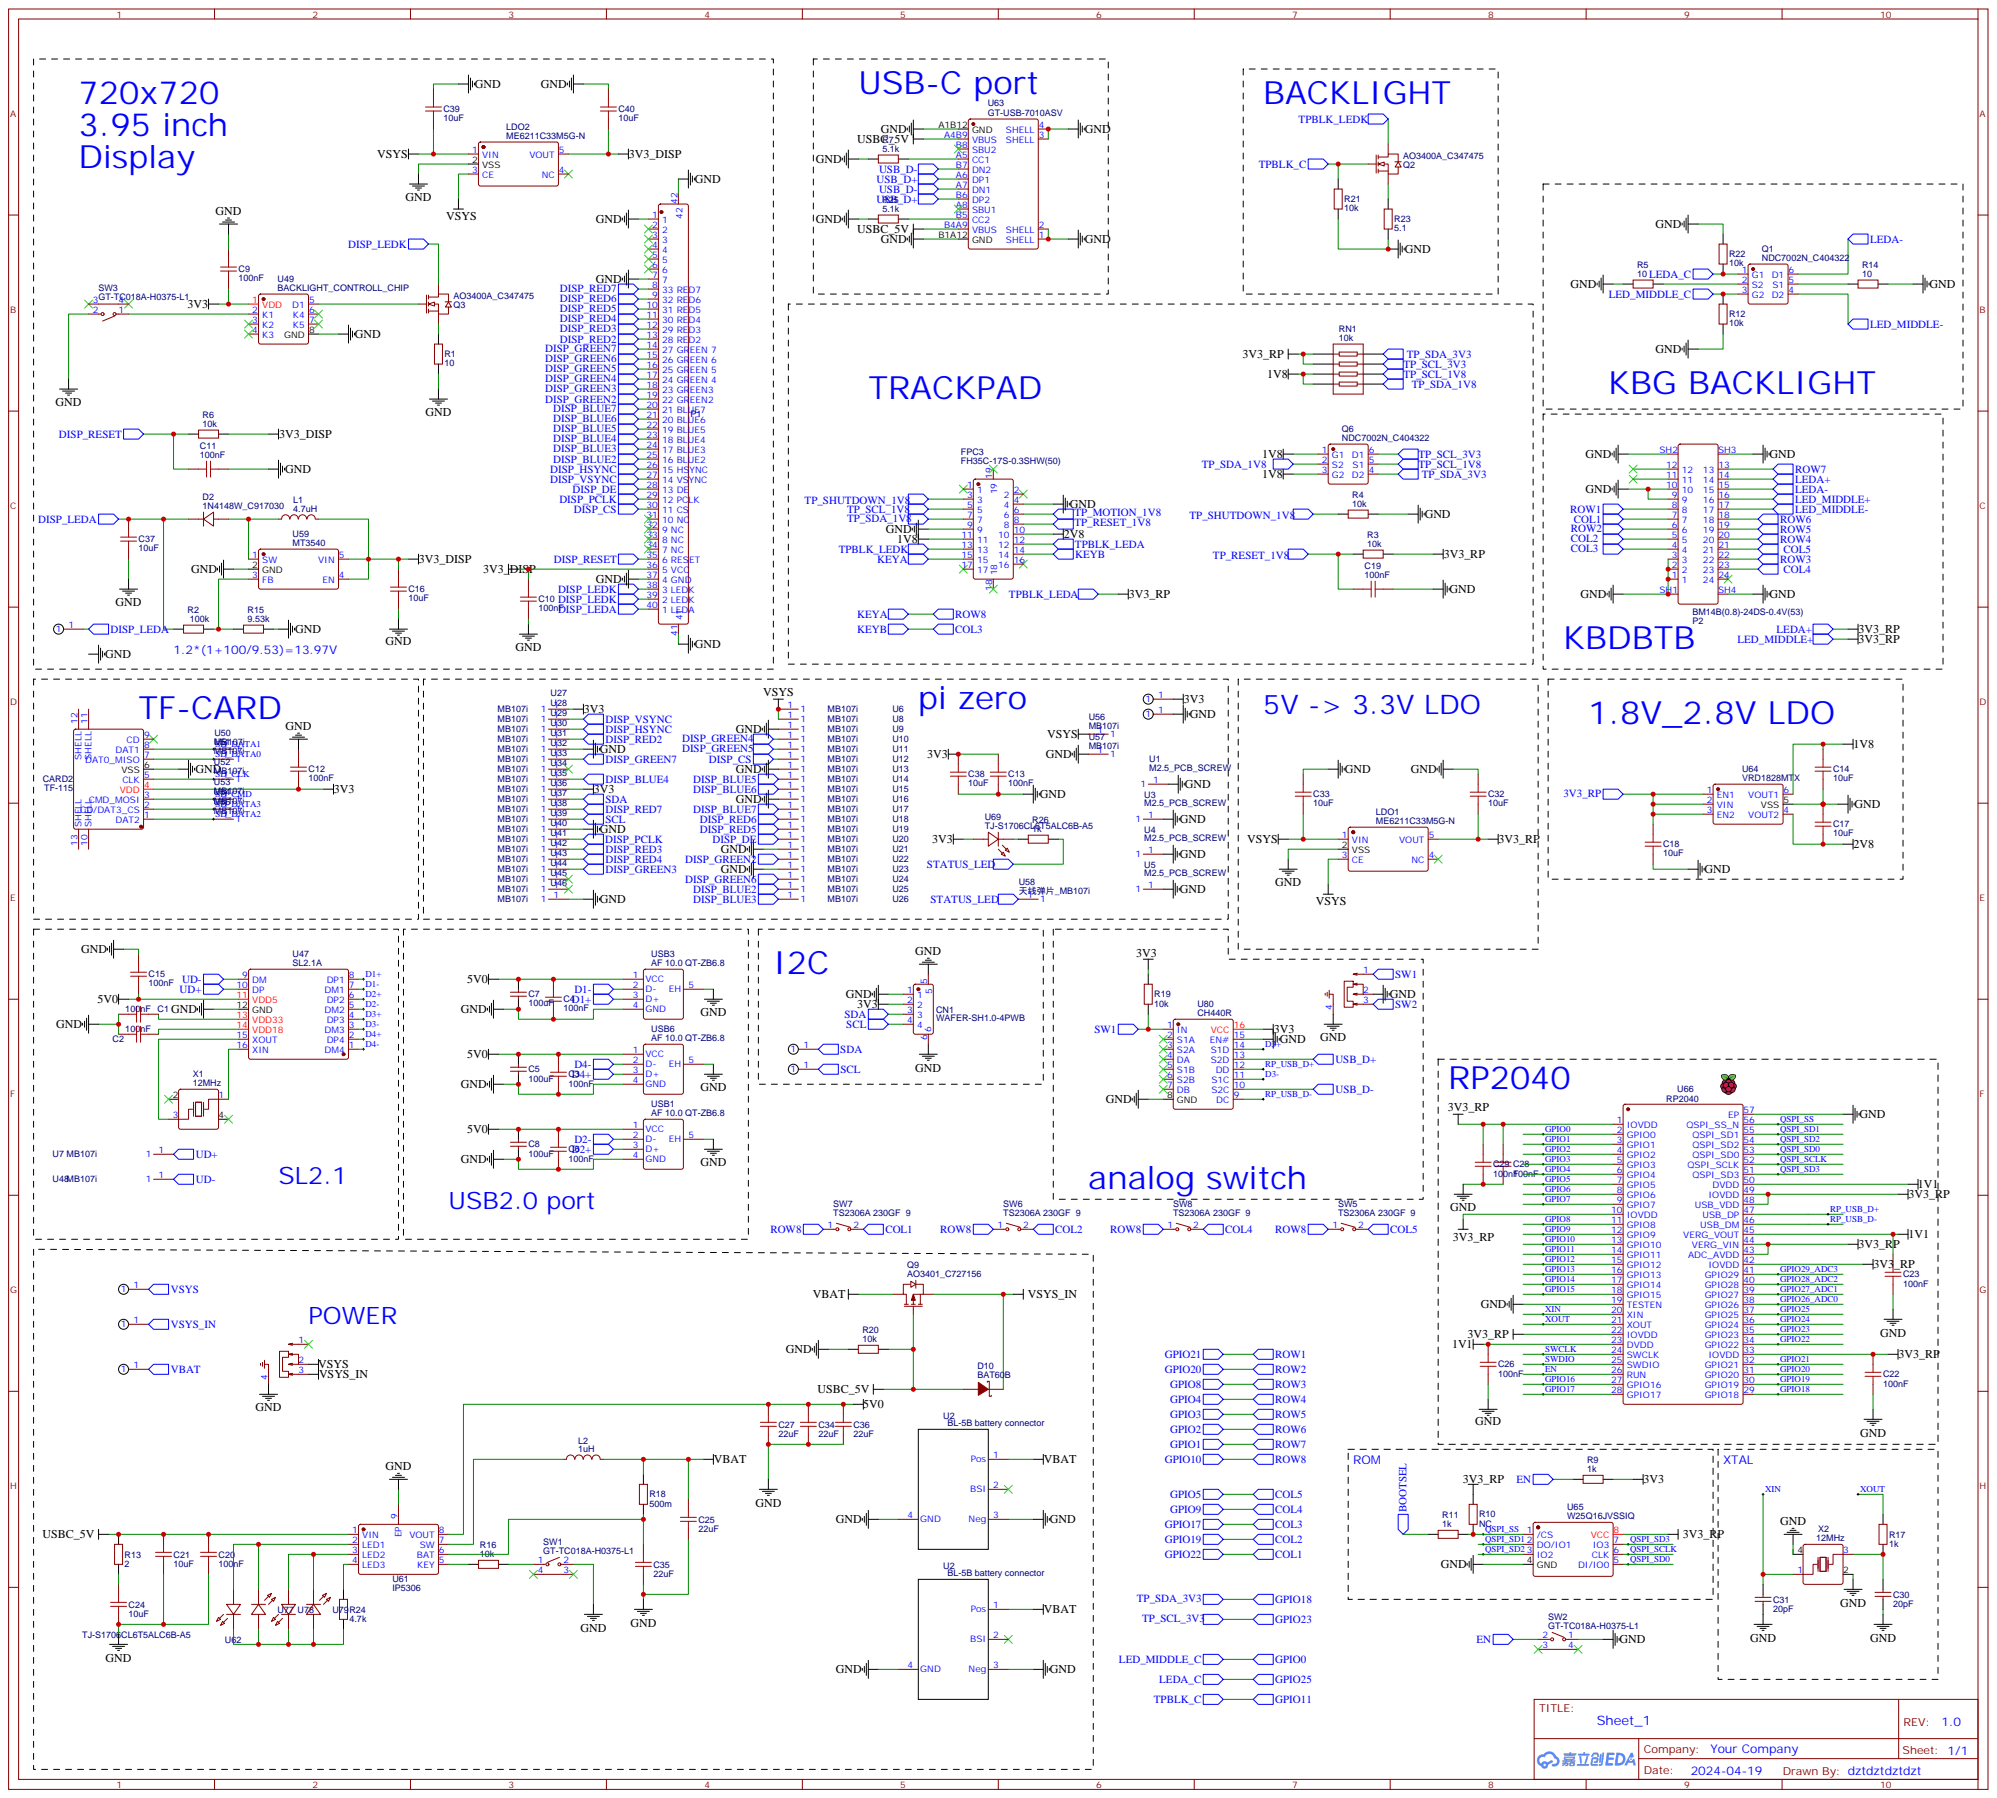
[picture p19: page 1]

SHELL 10 SHELL 11 SHELL 12 SHELL 13

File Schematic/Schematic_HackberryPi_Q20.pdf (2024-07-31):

# 1 LEDA 40 41 41 42 42

720x720

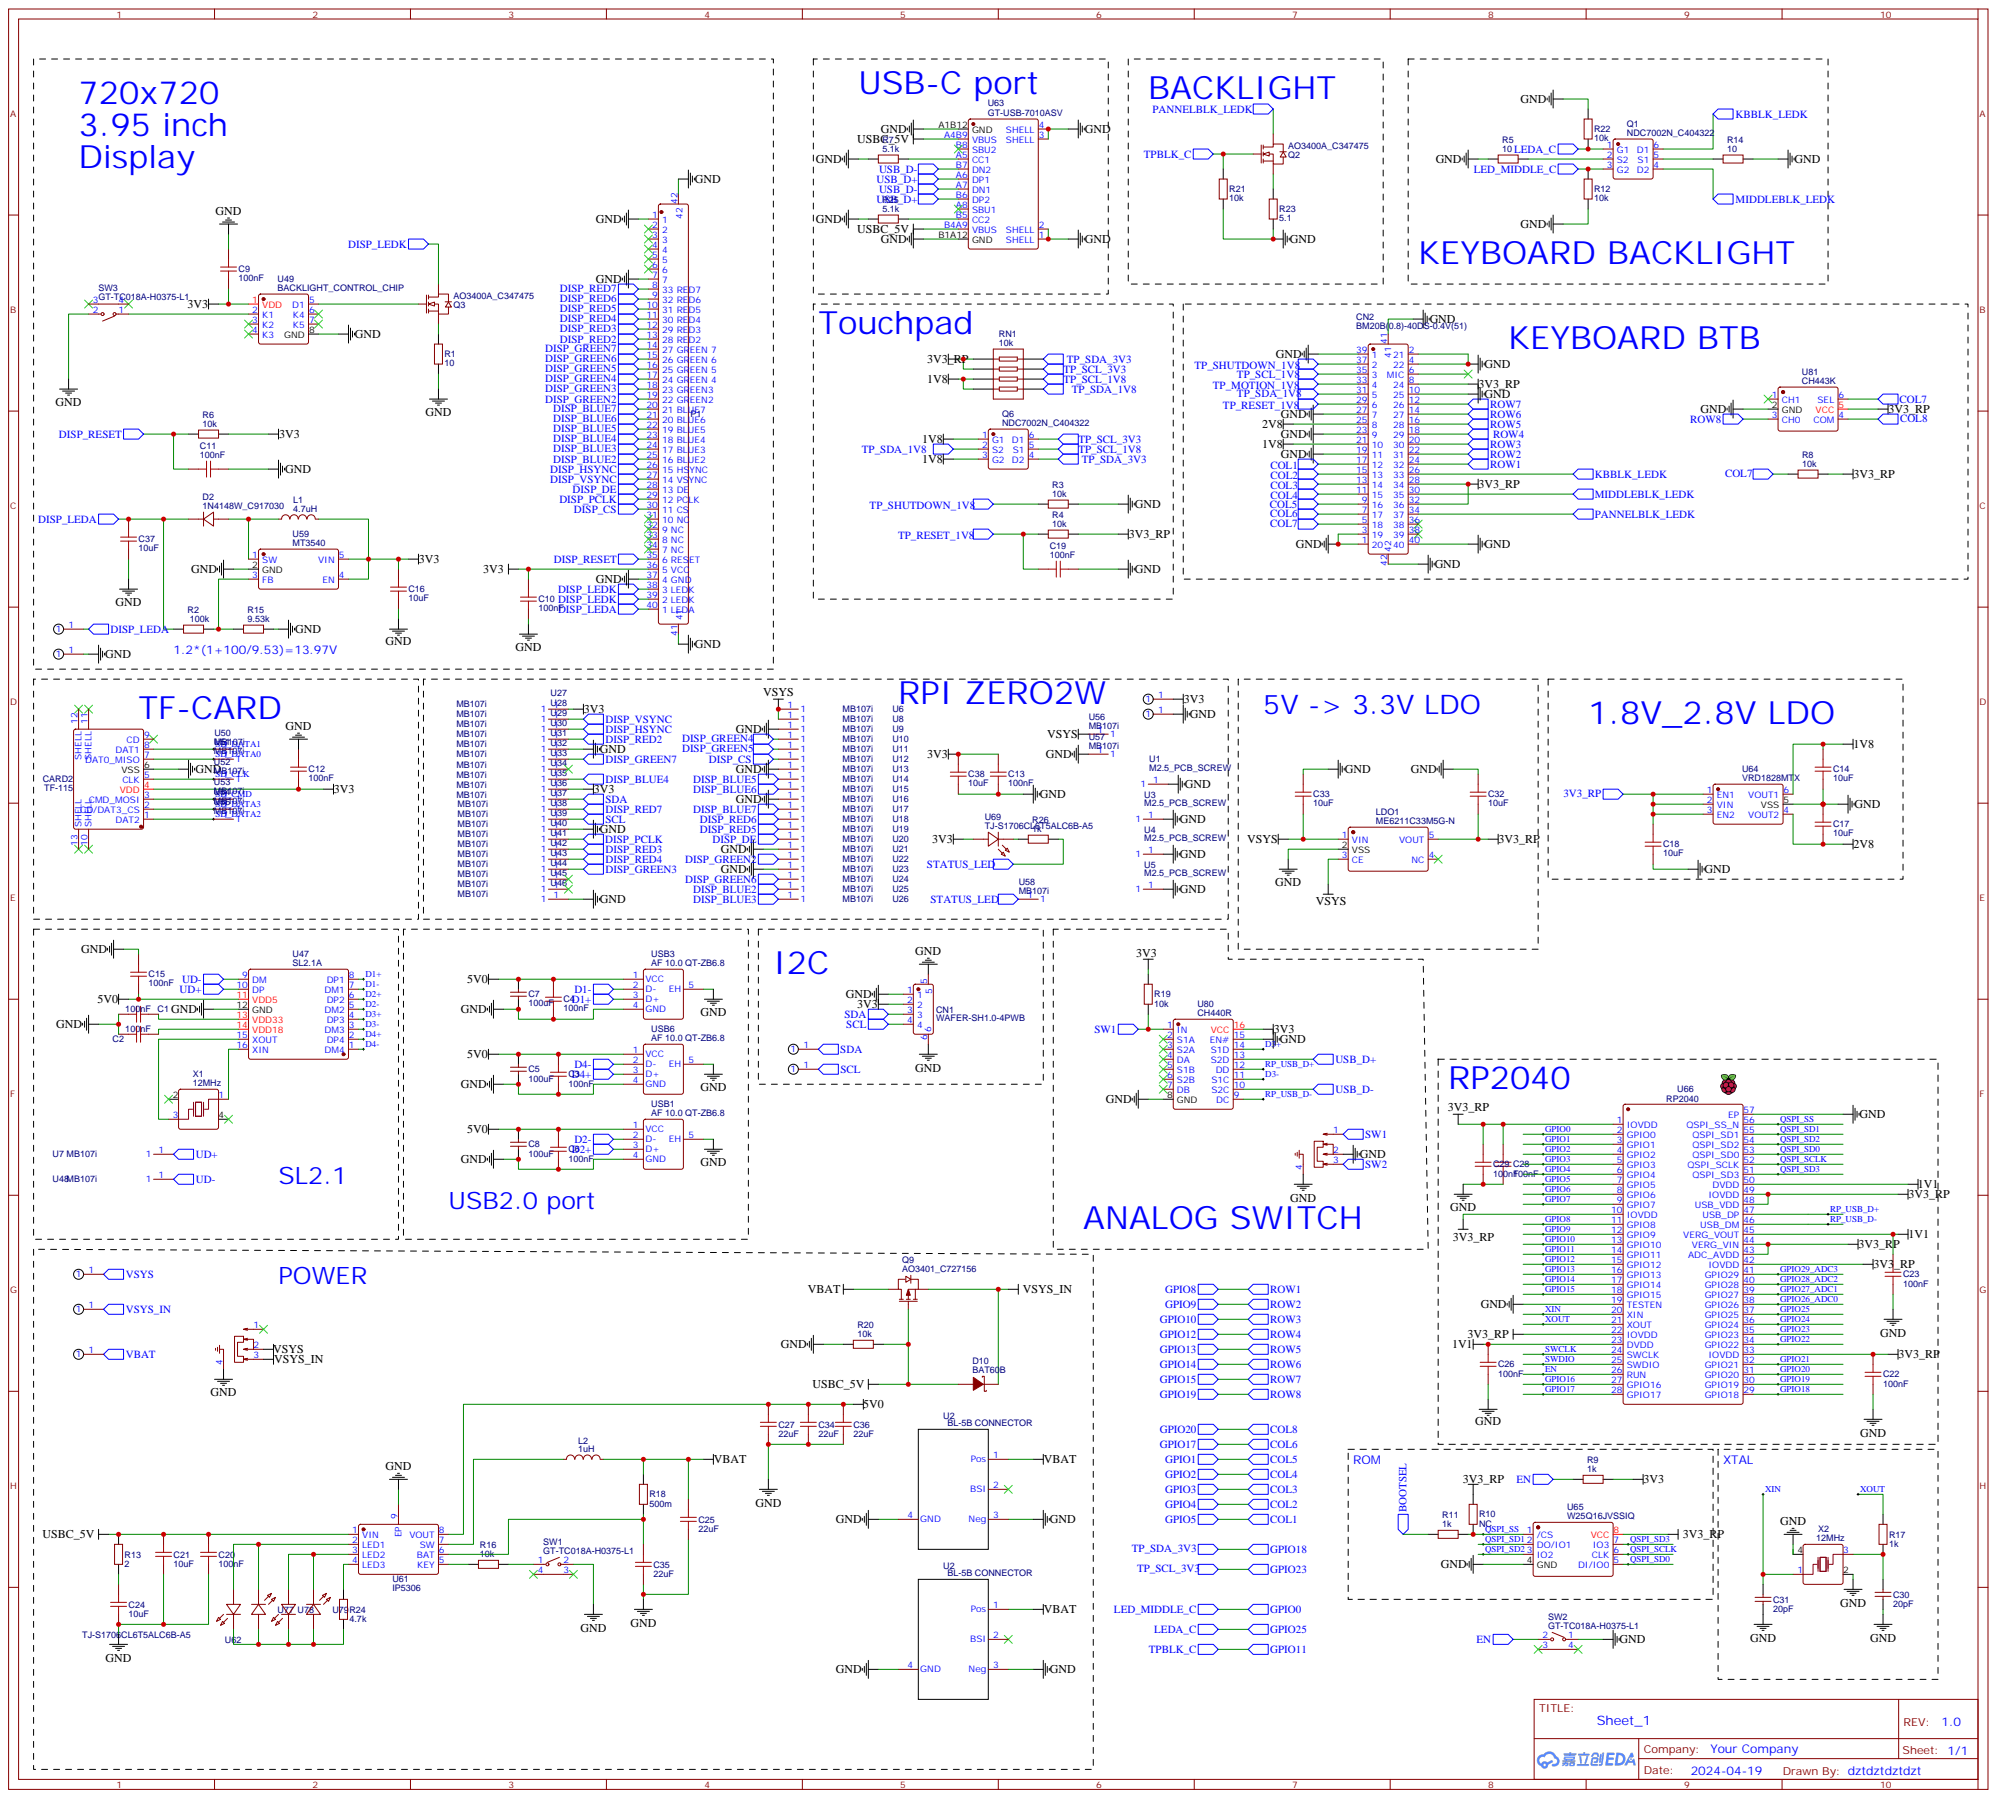
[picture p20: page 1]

SHELL 10 SHELL 11 SHELL 12 SHELL 13
